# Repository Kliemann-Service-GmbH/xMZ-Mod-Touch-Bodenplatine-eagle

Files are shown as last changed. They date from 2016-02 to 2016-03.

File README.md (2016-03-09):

# xMZ-Mod-Touch
## Eagle Dateien Bodenplatine

## Howto's
### Material Listen (BOM) erstellen

Die Material Listen werden aus den Eagle Zeichnungen gewonnen. Hierzu werden in
Eagle zunächst über den "design link" alle Bauteile in der Farnell Datenbank
gesucht. Anschließend wird diese Liste gespeicherti (Design Link Export).

* Dateiname: "Deckelplatine $VERSION-order.txt"

Danach wird das bom.ulp in Eagle ausgeführt. Folgende Einstellungen sind zu
wählen:

	Listen-Typ: Werte (Häckchen unter "Attribute auflisten" setzen)
	Ausgabeformat: CSV

Diese Datei wird ebenfalls gespeichert.

* Dateiname: "Deckelplatine $VERSION BOM.csv"

### Farnell BOM Import

Farnell bietet die Möglichkeit über eine Web GUI die BOM Daten in eine
Bestellung umzuwandeln.

Format der CSV Datei für den Import:
- 3 Spalten ("Anzahl;	Ordercode; Beschreibung")
- Dateiformat .xlsx oder .xls

#Produktionsdaten
## Dokumentation Boardlayout Dateien

Einige der wichtigsten Ebenen (Drill, Solder, Paste) wurden einzeln zusammen
mit der "Document" Ebene (Layer 48) als PDF gedruckt (Siehe Script generate_documentaiont.scr).
Dieses PDF kann mit dem Ghostscript tool `gs` in ein PDF gewandelt werden.

```
cd doc

gs -dBATCH -dNOPAUSE -q -sDEVICE=pdfwrite -sOutputFile=Bodenplatine.pdf \
Bodenplatine-DIMENSIONS.pdf \
Bodenplatine-BOM.pdf \
Bodenplatine-Placement_TOP.pdf \
Bodenplatine-TOP.pdf \
Bodenplatine-BOTTOM.pdf \
Bodenplatine-BOTTOM-Solder-Mask.pdf \
Bodenplatine-TOP-Paste-Mask.pdf \
Bodenplatine-Drill-Drawing.pdf \
```

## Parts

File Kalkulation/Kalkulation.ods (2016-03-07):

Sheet: Kalkulation
Pos | Hersteller | Lieferant | Bestellnummer Lieferant | Bezeichnung | Preis bei Abnahme von Menge | pro Board nötig | Einzelpreis | Gesamtpreis
1 | FAIRCHILD SEMICONDUCTOR - BAR4 | Farnell | 2453275 | BAR43 SCHOTTKY-DIODE, 30V, SOT-23-3 | 20 | 9 | ,1470 | 2,94
2 | MULTICOMP - MC01W08055270R | Farnell | 9334254 | DICKSCHICHTWIDERSTAND 270R 5% 0.1W 0805 | 50 | 9 | ,0370 | 1,85
3 | MULTICOMP - MC0063W060352K2 | Farnell | 9331913 | DICKSCHICHTWIDERSTAND 2K2 5% 0.063W 0603 | 20 | 9 | ,0104 | 0,21
4 | TE CONNECTIVITY / NEOHM - CPF0 | Farnell | 1697388 | DÜNNSCHICHTWIDERST. 10K 0.1% 0.063W 0603 | 30 | 9 | ,3550 | 10,65
5 | NXP – BC846,215 | Farnell | 1081227 | TRANSISTOR, NPN, 65V, SOT-23 | 20 | 9 | ,0370 | 0,74
6 | KINGBRIGHT - KP-3216SYC - LED | Farnell | 8529990 | LED, SMD 1206 IN GELB 590NM 120GRAD | 10 | 9 | ,2250 | 2,25
7 | VISHAY - LL4148-GS08 - DIODE | Farnell | 9549986 | DIODE, SCHNELL SCHALTEND, 100V, SOD-80 | 100 | 9 | ,0241 | 2,41
8 | TE CONNECTIVITY V23061B1005A301 | Farnell | 1023958 | RELAIS, SPDT, 250VAC, 8A | 10 | 9 | 2,1300 | 21,30
9 | SCHURTER - 3101.0040 | Farnell | 1222690 | SICHERUNGSHALTER FPG4 VERT PCB | 12 | 12 | ,8840 | 10,61
10 | www.wppro.com | Conrad | 739630 - 62 | Stiftleiste, gerade Rastermaß: 2.54 mm Polzahl Gesamt: 20 | 1 | 1 | ,3100 | 0,31
11 | metz-connect.com | METZ-Connect | AST12510 | ST125xxVDNN (AST125) | ? | 10 | ? | #VALUE!
12 | metz-connect.com | METZ-Connect | AST1256 | ST125xxVDNN (AST125) | ? | 1 | ? | #VALUE!
13 | metz-connect.com | METZ-Connect | AST1258 | ST125xxVDNN (AST125) | ? | 2 | ? | #VALUE!
14 | TAIWAY | as-electronic.net | 200A-WMSP3-P2B4M2GE | Sub-Miniature Toggle Switches on-off-on | ? | 9 | ? | #VALUE!
15 | WAGO | Farnell | 1283526 | Wire-To-Board-Reihenklemme, 2, 320 V, 24 A, 28 AWG, 12 AWG, 2.5 mm² | 1 | 1 | ,6100 | 0,61
16 | WAGO | Farnell | 1283527 | Wire-To-Board-Reihenklemme, 3, 320 V, 24 A, 28 AWG, 12 AWG, 2.5 mm² | 1 | 1 | ,8790 | 0,88

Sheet: Lager
Nr | Lieferant | Bestellnummer Lieferant | Bezeichnung | Mindestbestellmenge | im Lager vorhanden
1 | Farnell | 2453275 | BAR43 SCHOTTKY-DIODE, 30V, SOT-23-3 | 20 | 2
2 | Farnell | 9334254 | DICKSCHICHTWIDERSTAND 270R 5% 0.1W 0805 | 50 | 30
3 | Farnell | 9331913 | DICKSCHICHTWIDERSTAND 2K2 5% 0.063W 0603 | 20 | 1
4 | Farnell | 1697388 | DÜNNSCHICHTWIDERST. 10K 0.1% 0.063W 0603 | 30 | 9
5 | Farnell | 1081227 | TRANSISTOR, NPN, 65V, SOT-23 | 10 | 9
6 | Farnell | 8529990 | LED, SMD 1206 IN GELB 590NM 120GRAD | 10 | 10
7 | Farnell | 9549986 | DIODE, SCHNELL SCHALTEND, 100V, SOD-80 | 100 | 80
8 | Farnell | 1023958 | RELAIS, SPDT, 250VAC, 8A | 10 | 1
9 | Farnell | 1283526 | Wire-To-Board-Reihenklemme, 2, 320 V, 24 A, 28 AWG, 12 AWG, 2.5 mm² | 1 | 50
10 | Farnell | 1283527 | Wire-To-Board-Reihenklemme, 3, 320 V, 24 A, 28 AWG, 12 AWG, 2.5 mm² | 1 | 50

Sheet: BOM
Qty | Value | Part Num | Package | Parts | Hersteller | Datenblatt
9 | 1N4148W | LL4148-GS08 | MINIMELF | V5, V6, V7, V8, V13, V14, V15, V16, V18 | VISHAY - LL4148-GS08 - DIODE | LL4148_1353494.pdf
9 | 2k2 | MC0063W060352K2 | R0603 | R5, R6, R7, R8, R17, R18, R19, R20, R26 | MULTICOMP - MC0063W060352K2 | R2k2_1788326.pdf
10 | 3,15AT | 3101.0040 | FPG4 | F1, F2, F3, F4, F5, F6, F7, F8, F9, F13 | SCHURTER - 3101.0040 | FUSEHOLDER_PL_FPG_4-40.pdf
1 | 6,3AT | 3101.0040 | FPG4 | F12 | SCHURTER - 3101.0040 | FUSEHOLDER_PL_FPG_4-40.pdf
1 | 10AT | 3101.0040 | FPG4 | F10 | SCHURTER - 3101.0040 | FUSEHOLDER_PL_FPG_4-40.pdf
9 | 10k | CPF0603B10KE1 | R0603 | R9, R10, R11, R12, R21, R22, R23, R24, R27 | TE CONNECTIVITY / NEOHM - CPF0 | R10k_1786677.pdf
1 | 236-402 | 236-402 | P-236-402 | X15 | WAGO | WAGO236_Connector Banana Pro Power SATA-WAGO236-402_WAGO236-403_WAGO236-404#WAG.pdf
1 | 236-403 | 236-403 | P-236-403 | X14 | WAGO | WAGO236_Connector Banana Pro Power SATA-WAGO236-402_WAGO236-403_WAGO236-404#WAG.pdf
9 | 270R | MC01W08055270R | M0805 | R1, R2, R3, R4, R13, R14, R15, R16, R25 | MULTICOMP - MC01W08055270R | R270_1716700.pdf
9 | BAR43SOT233 | BAR43 | SOT23 | V1, V2, V3, V4, V9, V10, V11, V12, V17 | FAIRCHILD SEMICONDUCTOR - BAR4 | BAR43_1963228.pdf
9 | BC846BLT1SMD | BC846,215 | SOT23 | Q1, Q2, Q3, Q4, Q5, Q6, Q7, Q8, Q9 | NXP – BC846,215 | BC846BWT1G_1907697.pdf
4 | MOUNT-PAD-ROUND3.3 | * | 3,3-PAD | H1, H2, H3, H4
9 | RY612012 | V23061B1005A301 | RY-II | K1, K2, K3, K4, K5, K6, K7, K8, K9 | TE CONNECTIVITY V23061B1005A301 | SCHRACK_V23061-B1007-A301_MSR_0611.pdf
1 | SPRINGCON_AST125_3X2 | * | RM 2.54 | X10 | METZ-Connect | METZ-Connect_AST125_Data_sheet_AST125_ST125xxVDNN_OFF-023654P.pdf
2 | SPRINGCON_AST125_4X2 | * | RM 2.54 | X11, X12 | METZ-Connect | METZ-Connect_AST125_Data_sheet_AST125_ST125xxVDNN_OFF-023654P.pdf
10 | SPRINGCON_AST125_5X2 | * | RM 2.54 | X1, X2, X3, X4, X5, X6, X7, X8, X9, X13 | METZ-Connect | METZ-Connect_AST125_Data_sheet_AST125_ST125xxVDNN_OFF-023654P.pdf
1 | Stiftleiste 2x20 pol | * | 2X10 | JP1 | www.wppro.com | 739630-da-01-ml-WANNENSTIFTLEISTE_GERADE_RM_2_54_2_de_en.pdf
9 | TL39PO | A103SYCQ04 | TL3XPO | S1, S2, S3, S4, S5, S6, S7, S8, S9 | TAIWAY | Series 200A-C (Sealed) Sub-Miniature Toggle Switches 17_3079_proFpath.pdf
9 | YELLOW | KP-3216SYC | LED-1206 | D1, D2, D3, D4, D5, D6, D7, D8, D9 | KINGBRIGHT - KP-3216SYC - LED | LED_55733.pdf

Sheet: Bodenplatine_ListByValues
Qty | Value | Part Num | Package | Parts
9 | 1N4148W | LL4148-GS08 | MINIMELF | V5, V6, V7, V8, V13, V14, V15, V16, V18
9 | 2k2 | MC0063W060352K2 | R0603 | R5, R6, R7, R8, R17, R18, R19, R20, R26
10 | 3,15AT | 3101.0040 | FPG4 | F1, F2, F3, F4, F5, F6, F7, F8, F9, F13
1 | 6,3AT | 3101.0040 | FPG4 | F12
1 | 10AT | 3101.0040 | FPG4 | F10
9 | 10k | CPF0603B10KE1 | R0603 | R9, R10, R11, R12, R21, R22, R23, R24, R27
1 | 236-402 | 236-402 | P-236-402 | X15
1 | 236-403 | 236-403 | P-236-403 | X14
9 | 270R | MC01W08055270R | M0805 | R1, R2, R3, R4, R13, R14, R15, R16, R25
9 | BAR43SOT233 | BAR43 | SOT23 | V1, V2, V3, V4, V9, V10, V11, V12, V17
9 | BC846BLT1SMD | BC846,215 | SOT23 | Q1, Q2, Q3, Q4, Q5, Q6, Q7, Q8, Q9
4 | MOUNT-PAD-ROUND3.3 | * | 3,3-PAD | H1, H2, H3, H4
9 | RY612012 | V23061B1005A301 | RY-II | K1, K2, K3, K4, K5, K6, K7, K8, K9
1 | SPRINGCON_AST125_3X2 | * | SPRINGCON_AST125_3X2 | X10
2 | SPRINGCON_AST125_4X2 | * | SPRINGCON_AST125_4X2 | X11, X12
10 | SPRINGCON_AST125_5X2 | * | SPRINGCON_AST125_5X2 | X1, X2, X3, X4, X5, X6, X7, X8, X9, X13
1 | Stiftleiste 2x20 pol | * | 2X10 | JP1
9 | TL39PO | A103SYCQ04 | TL3XPO | S1, S2, S3, S4, S5, S6, S7, S8, S9
9 | YELLOW | KP-3216SYC | LED-1206 | D1, D2, D3, D4, D5, D6, D7, D8, D9

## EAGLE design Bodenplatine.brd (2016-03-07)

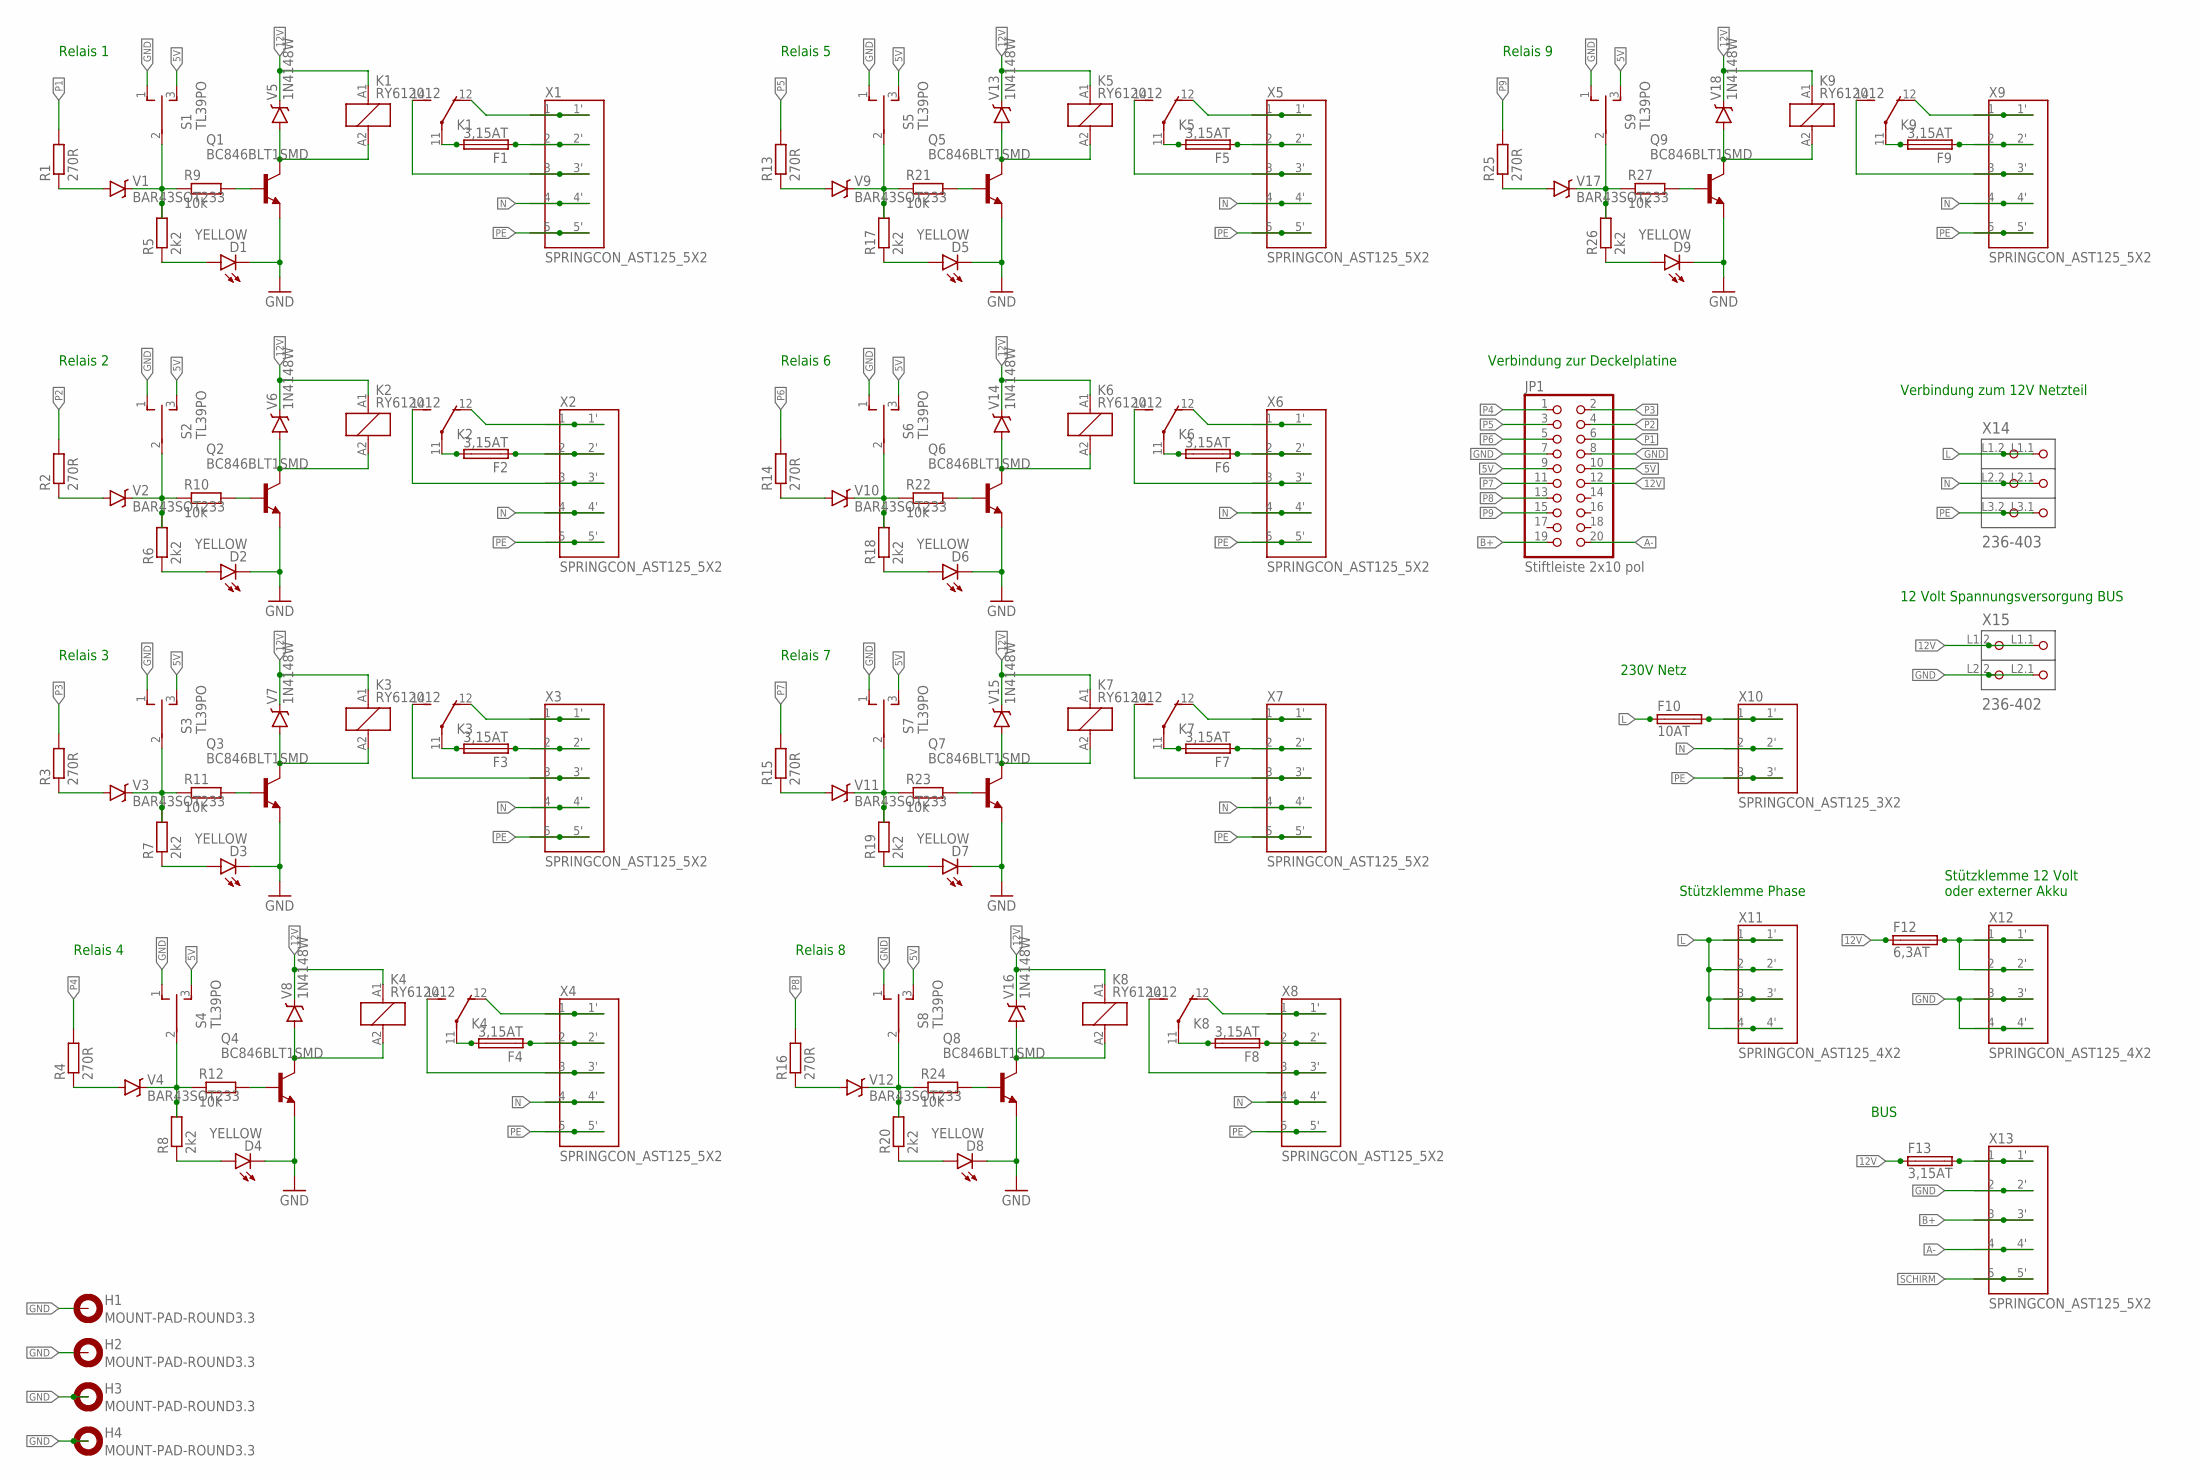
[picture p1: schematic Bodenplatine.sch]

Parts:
D1, D2, D3, D4, D5, D6, D7, D8, D9: YELLOW; LED-1206; MPN KP-3216SYC
F1, F2, F3, F4, F5, F6, F7, F8, F9, F13: 3,15AT; FPG4; MPN 3101.0040
F10: 10AT; FPG4; MPN 3101.0040
F12: 6,3AT; FPG4; MPN 3101.0040
H1, H2, H3, H4: MOUNT-PAD-ROUND3.3; 3,3-PAD
JP1: Stiftleiste 2x10 pol; 2X10
K1, K2, K3, K4, K5, K6, K7, K8, K9: RY612012; RY-II; MPN V23061B1005A301
Q1, Q2, Q3, Q4, Q5, Q6, Q7, Q8, Q9: BC846BLT1SMD; SOT23; MPN BC846,215
R1, R2, R3, R4, R13, R14, R15, R16, R25: 270R; M0805; MPN MC01W08055270R
R5, R6, R7, R8, R17, R18, R19, R20, R26: 2k2; R0603; MPN MC0063W060352K2
R9, R10, R11, R12, R21, R22, R23, R24, R27: 10k; R0603; MPN CPF0603B10KE1
S1, S2, S3, S4, S5, S6, S7, S8, S9: TL39PO; TL3XPO; MPN A103SYCQ04
V1, V2, V3, V4, V9, V10, V11, V12, V17: BAR43SOT233; SOT23; MPN BAR43
V5, V6, V7, V8, V13, V14, V15, V16, V18: 1N4148W; MINIMELF; MPN LL4148-GS08
X1, X2, X3, X4, X5, X6, X7, X8, X9, X13: SPRINGCON_AST125_5X2
X10: SPRINGCON_AST125_3X2
X11, X12: SPRINGCON_AST125_4X2
X14: 236-403; P-236-403; MPN 236-403
X15: 236-402; P-236-402; MPN 236-402

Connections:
5V: JP1.9, JP1.10, S1.3 (S), S2.3 (S), S3.3 (S), S4.3 (S), S5.3 (S), S6.3 (S), S7.3 (S), S8.3 (S), S9.3 (S)
12V: F12.1, F13.1, JP1.12, K1.A1 (1), K2.A1 (1), K3.A1 (1), K4.A1 (1), K5.A1 (1), K6.A1 (1), K7.A1 (1), K8.A1 (1), K9.A1 (1), V5.C, V6.C, V7.C, V8.C, V13.C, V14.C, V15.C, V16.C, V18.C, X15.L1.1 (P1.1), X15.L1.2 (P1.2)
A-: JP1.20, X13.4, X13.4' (4)
B+: JP1.19, X13.3, X13.3' (3)
GND: D1.C, D2.C, D3.C, D4.C, D5.C, D6.C, D7.C, D8.C, D9.C, H1.B3,3, H2.B3,3, H3.B3,3, H4.B3,3, JP1.7, JP1.8, Q1.2 (E), Q2.2 (E), Q3.2 (E), Q4.2 (E), Q5.2 (E), Q6.2 (E), Q7.2 (E), Q8.2 (E), Q9.2 (E), S1.1 (O), S2.1 (O), S3.1 (O), S4.1 (O), S5.1 (O), S6.1 (O), S7.1 (O), S8.1 (O), S9.1 (O), X12.3, X12.3' (3), X12.4, X12.4' (4), X13.2, X13.2' (2), X15.L2.1 (P2.1), X15.L2.2 (P2.2)
L: F10.1, X11.1, X11.1' (1), X11.2, X11.2' (2), X11.3, X11.3' (3), X11.4, X11.4' (4), X14.L1.1 (P1.1), X14.L1.2 (P1.2)
N: X1.4, X1.4' (4), X2.4, X2.4' (4), X3.4, X3.4' (4), X4.4, X4.4' (4), X5.4, X5.4' (4), X6.4, X6.4' (4), X7.4, X7.4' (4), X8.4, X8.4' (4), X9.4, X9.4' (4), X10.2, X10.2' (2), X14.L2.1 (P2.1), X14.L2.2 (P2.2)
unnamed: F2.1, X2.2, X2.2' (2)
unnamed: K2.14 (S), X2.3, X2.3' (3)
unnamed: F2.2, K2.11
unnamed: K2.12 (O), X2.1, X2.1' (1)
unnamed: K2.A2 (2), Q2.3 (C), V6.A
unnamed: K3.14 (S), X3.3, X3.3' (3)
unnamed: R2.1, V2.1 (A)
unnamed: R6.2, R10.1, S2.2, V2.3 (C)
unnamed: D2.A, R6.1
unnamed: Q2.1 (B), R10.2
unnamed: F3.2, K3.11
unnamed: R3.1, V3.1 (A)
unnamed: R7.2, R11.1, S3.2, V3.3 (C)
unnamed: D3.A, R7.1
unnamed: Q3.1 (B), R11.2
unnamed: K3.A2 (2), Q3.3 (C), V7.A
unnamed: F3.1, X3.2, X3.2' (2)
unnamed: K3.12 (O), X3.1, X3.1' (1)
unnamed: K4.14 (S), X4.3, X4.3' (3)
unnamed: F4.2, K4.11
unnamed: R4.1, V4.1 (A)
unnamed: R8.2, R12.1, S4.2, V4.3 (C)
unnamed: D4.A, R8.1
unnamed: Q4.1 (B), R12.2
unnamed: K4.A2 (2), Q4.3 (C), V8.A
unnamed: F4.1, X4.2, X4.2' (2)
unnamed: K4.12 (O), X4.1, X4.1' (1)
unnamed: K5.14 (S), X5.3, X5.3' (3)
unnamed: F5.2, K5.11
unnamed: R13.1, V9.1 (A)
unnamed: R17.2, R21.1, S5.2, V9.3 (C)
unnamed: D5.A, R17.1
unnamed: Q5.1 (B), R21.2
unnamed: K5.A2 (2), Q5.3 (C), V13.A
unnamed: F5.1, X5.2, X5.2' (2)
unnamed: K5.12 (O), X5.1, X5.1' (1)
unnamed: K6.14 (S), X6.3, X6.3' (3)
unnamed: F6.2, K6.11
unnamed: R14.1, V10.1 (A)
unnamed: R18.2, R22.1, S6.2, V10.3 (C)
unnamed: D6.A, R18.1
unnamed: Q6.1 (B), R22.2
unnamed: K6.A2 (2), Q6.3 (C), V14.A
unnamed: F6.1, X6.2, X6.2' (2)
unnamed: K6.12 (O), X6.1, X6.1' (1)
unnamed: K7.14 (S), X7.3, X7.3' (3)
unnamed: F7.2, K7.11
unnamed: R15.1, V11.1 (A)
unnamed: R19.2, R23.1, S7.2, V11.3 (C)
unnamed: D7.A, R19.1
unnamed: Q7.1 (B), R23.2
unnamed: K7.A2 (2), Q7.3 (C), V15.A
unnamed: F7.1, X7.2, X7.2' (2)
unnamed: K7.12 (O), X7.1, X7.1' (1)
unnamed: K8.14 (S), X8.3, X8.3' (3)
unnamed: F8.2, K8.11
unnamed: R16.1, V12.1 (A)
unnamed: R20.2, R24.1, S8.2, V12.3 (C)
unnamed: D8.A, R20.1
unnamed: Q8.1 (B), R24.2
unnamed: K8.A2 (2), Q8.3 (C), V16.A
unnamed: F8.1, X8.2, X8.2' (2)
unnamed: K8.12 (O), X8.1, X8.1' (1)
unnamed: K9.14 (S), X9.3, X9.3' (3)
unnamed: F9.2, K9.11
unnamed: R25.1, V17.1 (A)
unnamed: R26.2, R27.1, S9.2, V17.3 (C)
unnamed: D9.A, R26.1
unnamed: Q9.1 (B), R27.2
unnamed: K9.A2 (2), Q9.3 (C), V18.A
unnamed: F9.1, X9.2, X9.2' (2)
unnamed: K9.12 (O), X9.1, X9.1' (1)
unnamed: K1.14 (S), X1.3, X1.3' (3)
unnamed: F1.2, K1.11
unnamed: R1.1, V1.1 (A)
unnamed: R5.2, R9.1, S1.2, V1.3 (C)
unnamed: D1.A, R5.1
unnamed: Q1.1 (B), R9.2
unnamed: K1.A2 (2), Q1.3 (C), V5.A
unnamed: F1.1, X1.2, X1.2' (2)
unnamed: K1.12 (O), X1.1, X1.1' (1)
unnamed: F10.2, X10.1, X10.1' (1)
unnamed: F13.2, X13.1, X13.1' (1)
unnamed: F12.2, X12.1, X12.1' (1), X12.2, X12.2' (2)
P1: JP1.6, R1.2
P2: JP1.4, R2.2
P3: JP1.2, R3.2
P4: JP1.1, R4.2
P5: JP1.3, R13.2
P6: JP1.5, R14.2
P7: JP1.11, R15.2
P8: JP1.13, R16.2
P9: JP1.15, R25.2
PE: X1.5, X1.5' (5), X2.5, X2.5' (5), X3.5, X3.5' (5), X4.5, X4.5' (5), X5.5, X5.5' (5), X6.5, X6.5' (5), X7.5, X7.5' (5), X8.5, X8.5' (5), X9.5, X9.5' (5), X10.3, X10.3' (3), X14.L3.1 (P3.1), X14.L3.2 (P3.2)
SCHIRM: X13.5, X13.5' (5)

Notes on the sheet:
Relais 2
Relais 3
Relais 4
Relais 5
Relais 6
Relais 7
Relais 8
Relais 9
Relais 1
Verbindung zur Deckelplatine
230V Netz
Stützklemme Phase
Stützklemme 12 Volt oder externer Akku
BUS
Verbindung zum 12V Netzteil
12 Volt Spannungsversorgung BUS

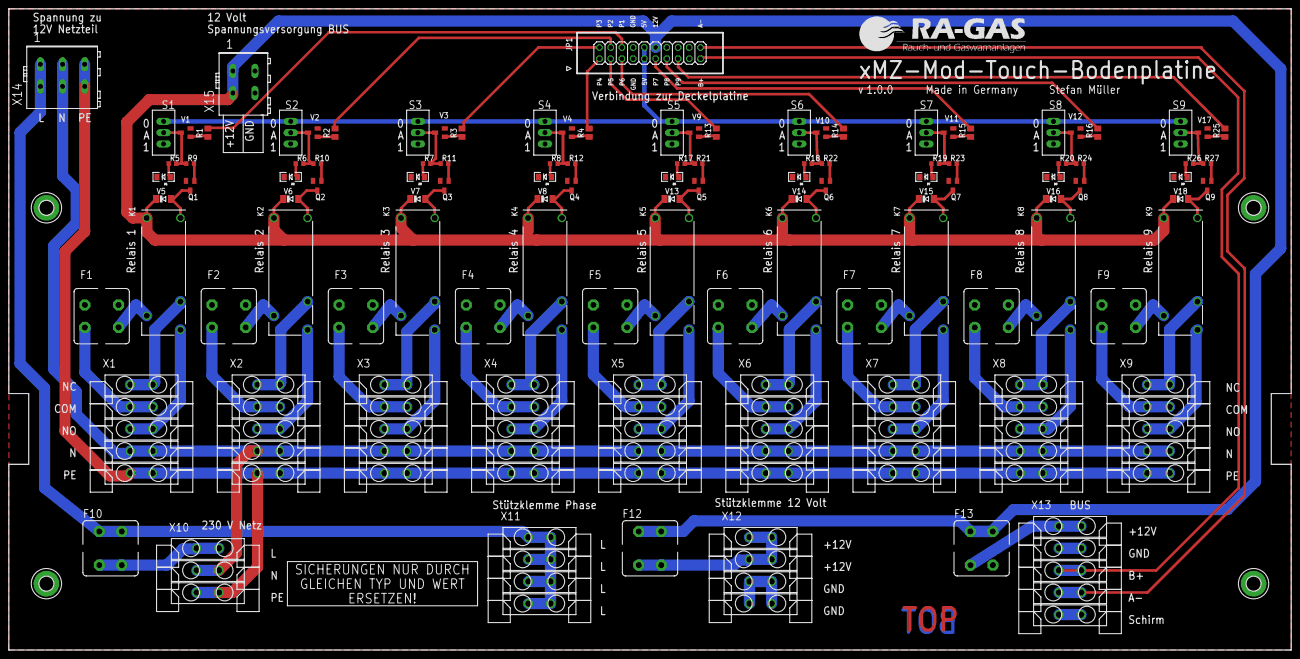
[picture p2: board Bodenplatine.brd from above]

Board: 2 copper layers, 290.0 x 145.0 mm, 118 parts (0 on the bottom side), 102 nets.

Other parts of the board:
DRILEGEND: DRILEGEND
U$1: TEXT_FUSE
U$2: TEXT_NAME_VERSION_AUTHOR
U$3: LOGO_RA-GAS
U$5: A3-LOC-RA-GAS

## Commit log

2016-02-25 Erste .gitignore Version
    Diese Version ignoriert die Eagle Sicherungskopien.
2016-02-25 Import Version v0.9.0 (v0.0.1)
    Aus dieser Version wurde der erste Prototyp von 'Conrad
    Leiterplattenservice' produziert. Der Aufdruck war leider v0.0.1, die
    richtige Versionsnummer lautete aber v0.9.0.
    [Bodenplatine v001-order.xlsx, Bodenplatine v090.brd, Bodenplatine v090.sch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]
2016-02-25 Import der Version v0.9.5
    Aus dieser Version wurde der zweite Prototype erstellt. Der Produzent
    war dieses Mal https://portal.multi-circuit-boards.eu
    [Bodenplatine v001-order.xlsx, Bodenplatine.brd, Bodenplatine.sch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]
2016-02-26 Anschluss Deckelplatine gegen verdrehen gesichert
    [Bodenplatine.brd, Bodenplatine.sch]
2016-03-07 Erste Version eines Scripts welches div. Layer mit einem Frame druckt
2016-03-07 Erste Version der 1.0.0 Produktionsdaten
    Versuch alle Datenblätter, eine Kalkulation und Lagerverwaltung und
    einer Eagle Datei mit "nur SMD" Bestückungsvariante. Zur Zeit noch nicht
    fertig.
    [Bodenplatine.brd, Bodenplatine.sch, DRILEGEND.CFG]
2016-03-07 Produktionsdaten exportiert. v1.0.0 soweit fertig
    [Bodenplatine.brd, Bodenplatine.sch, Kalkulation.ods]
2016-03-09 Kleine Aenderungen an der README
